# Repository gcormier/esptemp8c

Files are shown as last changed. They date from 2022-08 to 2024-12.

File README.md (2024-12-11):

# esptemp8c
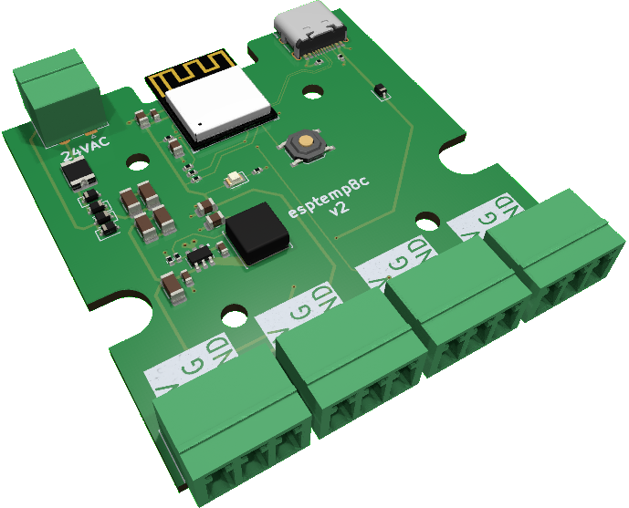
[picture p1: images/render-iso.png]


Open source, n-channel temperature logger using esphome for Dallas DS18B20 sensors. Powered by an ESP32-C3-MINI, it can be powered by USB-C or by 24VAC.



## Sensors
They can be found at various locations, including [DFRobot](https://www.dfrobot.com/product-689.html), [Adafruit](https://www.adafruit.com/product/381), Digikey or the usual suspects.

You will need to find out your sensor ID's as per the [esphome documentation](https://esphome.io/components/one_wire#one-wire).

### Counterfeit Sensors
If you are using a Dallas DS18B20 sensor, I strongly recommend using Digikey, Mouser or Adafruit to avoid obtaining [counterfeit sensors](https://github.com/cpetrich/counterfeit_DS18B20/tree/master).

## Powering
Only *one* power source should be used.
- USB-C Jack (5V)
- Screw terminal
    - It is designed for 24VAC. 12VAC is probably the minimum required for AC. Do not exceed 24VAC.
    - 9VDC will be the minimum required amount if using DC, and it has been tested up to 24VDC. 

A self-resetting polyfuse is included to protect HVAC equipment if sourcing 24VAC from these units. The polyfuse does NOT apply to power from the USB-C port, as the device supplying power should have overcurrent protection per the USB standard.

## Flashing / Programming
You must hold down the button while plugging in the device the first time to enter programming mode. The device will then show up as a USB device on your computer. You can then use the esphome flasher to flash the device.

Subsequent flashing does not require use of the button - it can be done via USBC or OTA as well.

## Enclosure
Fits in a [Hammond 1593KBK](https://www.hammfg.com/part/1593KBK). Or you can make your own enclosure and 3D-print it (contributions welcome).

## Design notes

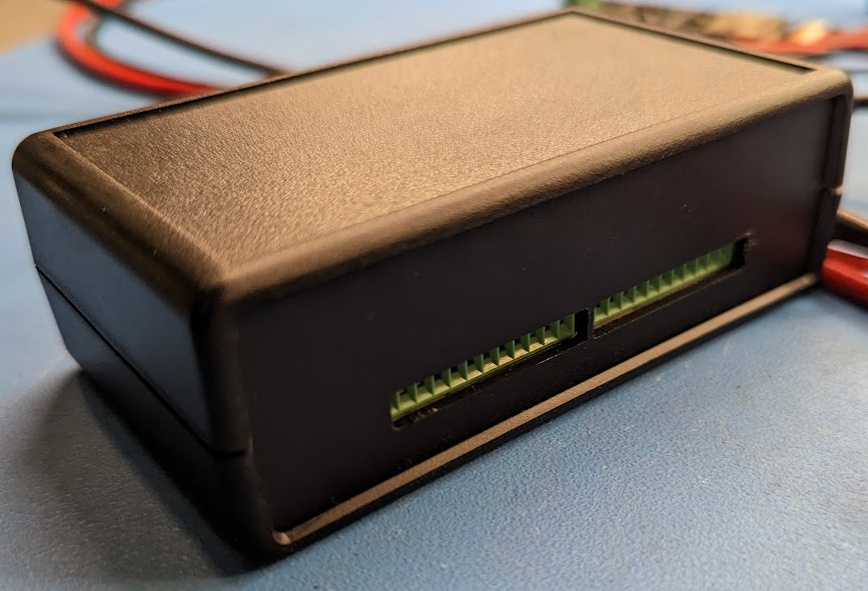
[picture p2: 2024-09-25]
images/case_v1.png

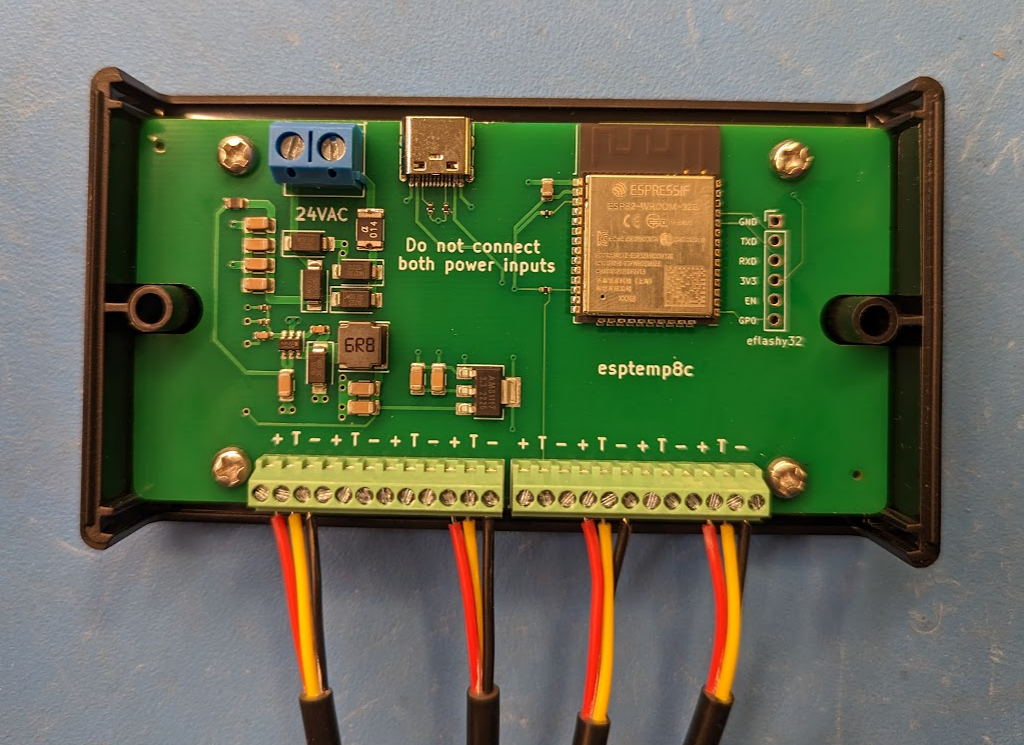
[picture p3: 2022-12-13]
images/esptemp8c_v1.png

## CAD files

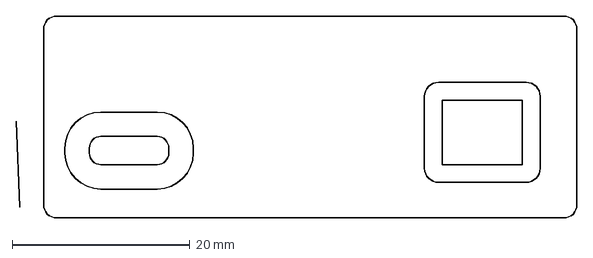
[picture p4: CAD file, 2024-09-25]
pcb/esptemp8c_panel1/panel1.dxf
63.1 x 22.7 mm

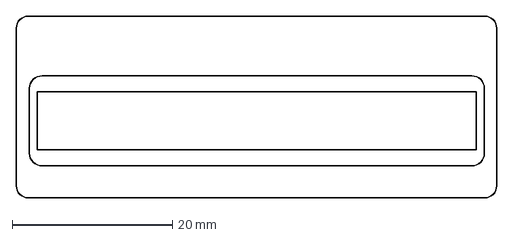
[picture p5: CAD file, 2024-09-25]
pcb/esptemp8c_panel2/panel2.dxf
60.0 x 22.7 mm

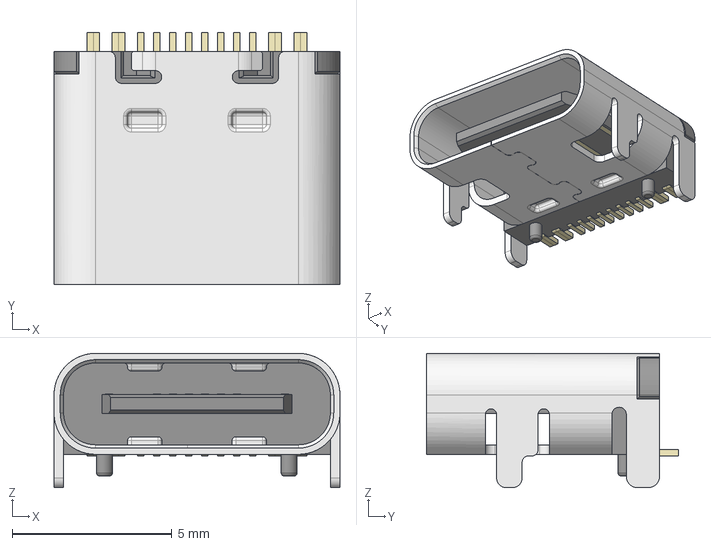
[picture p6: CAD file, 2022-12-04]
pcb/HRO_TYPE-C-31-M-12.step
8.95 x 7.90 x 4.20 mm

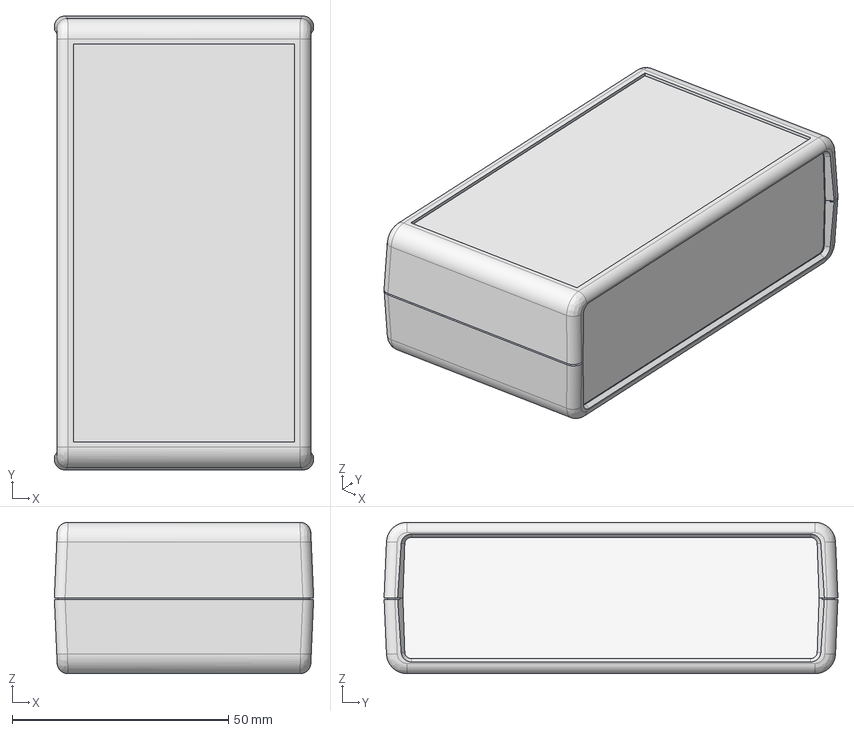
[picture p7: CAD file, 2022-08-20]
pcb/1593VBK.stp
60.0 x 105.0 x 35.0 mm
1593V Bottom v2
1593V End panel v1 x 2
1593V Top v2

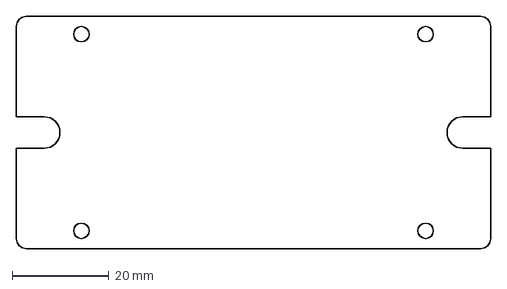
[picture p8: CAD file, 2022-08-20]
pcb/1593VBK_PCB.dxf
98.0 x 48.0 mm

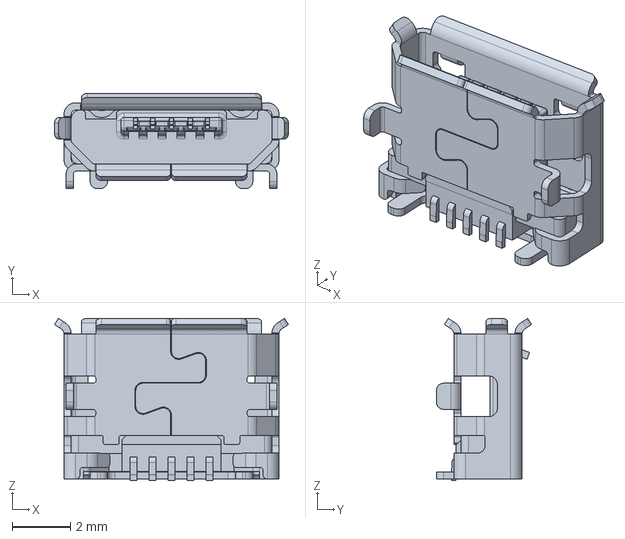
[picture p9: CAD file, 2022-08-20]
pcb/10118194c.stp
8.05 x 3.27 x 5.58 mm

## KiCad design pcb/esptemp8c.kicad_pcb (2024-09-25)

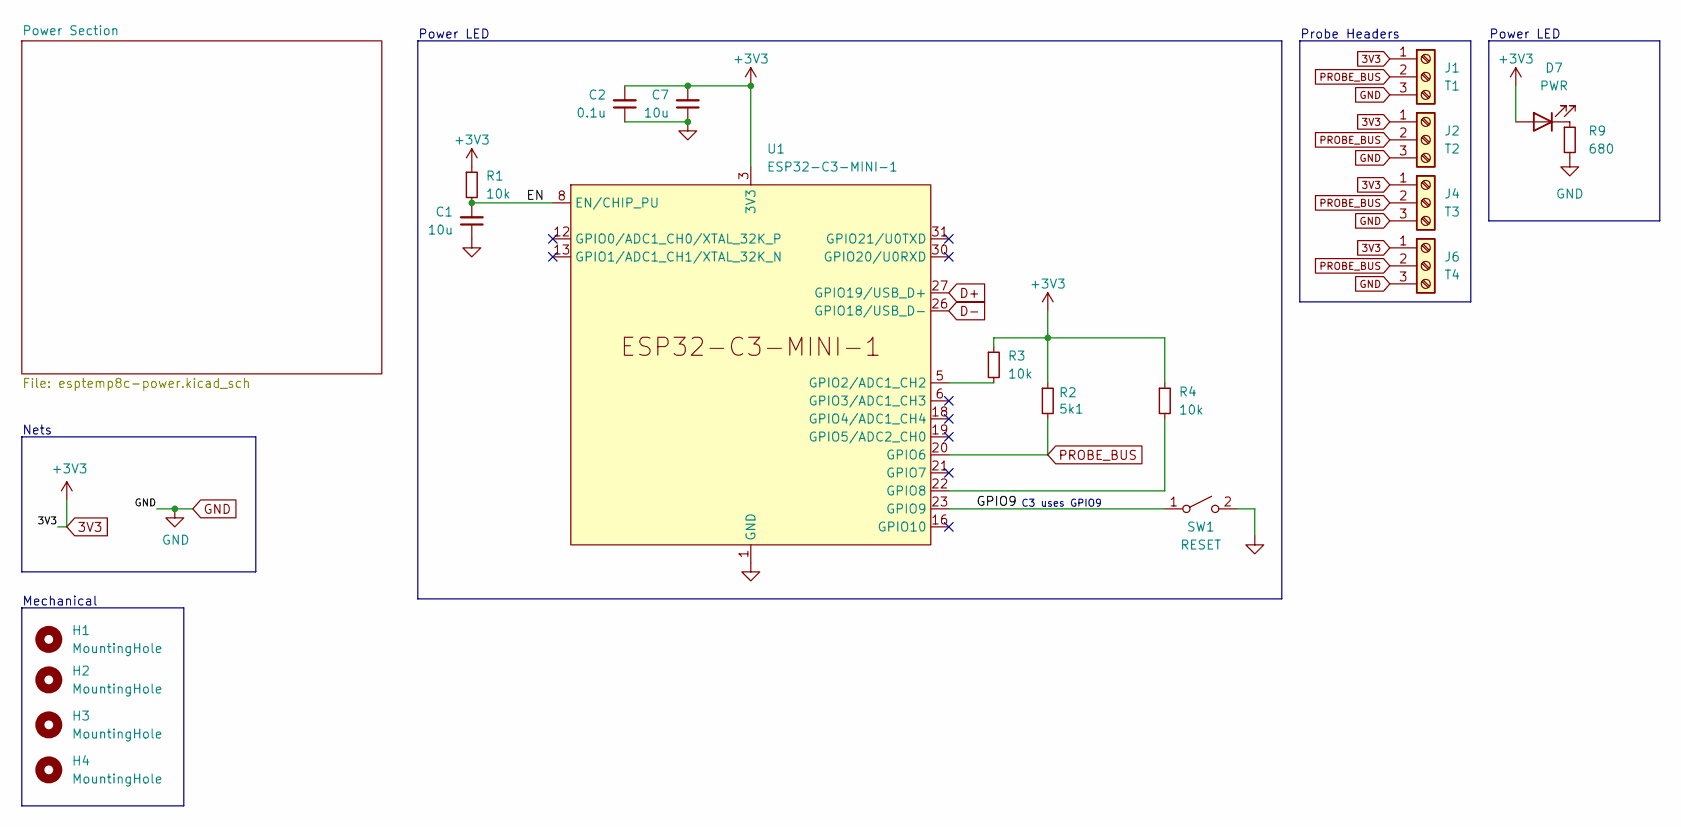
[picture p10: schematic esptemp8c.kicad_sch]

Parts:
C1, C7: 10u; C_0805_2012Metric; LCSC C15850
C2: 0.1u; C_0603_1608Metric; LCSC C14663
D7: PWR; LED_0805_2012Metric; LCSC C84256
H1, H2, H3, H4: MountingHole; MountingHole_3.2mm_M3
J1: T1; PhoenixContact_MC_1,5_3-G-3.81_1x03_P3.81mm_Horizontal; LCSC C8406
J2: T2; PhoenixContact_MC_1,5_3-G-3.81_1x03_P3.81mm_Horizontal; LCSC C8406
J4: T3; PhoenixContact_MC_1,5_3-G-3.81_1x03_P3.81mm_Horizontal; LCSC C8406
J6: T4; PhoenixContact_MC_1,5_3-G-3.81_1x03_P3.81mm_Horizontal; LCSC C8406
R1, R3, R4: 10k; R_0402_1005Metric; LCSC C25744
R2: 5k1; R_0402_1005Metric; LCSC C25905
R9: 680; R_0402_1005Metric; LCSC C25130
SW1: RESET; SW_Push_1P1T_XKB_TS-1187A; LCSC C318884
U1: ESP32-C3-MINI-1; LCSC C2838502

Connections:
3V3: C2.2, C7.2, D7.2 (A), J1.1, J2.1, J4.1, J6.1, R1.1, R2.1, R3.1, R4.1, U1.3 (3V3); also elsewhere on the board
/EN: C1.2, R1.2, U1.8 (EN/CHIP_PU)
/GPIO9: SW1.1 (A), U1.23 (GPIO9)
D+: U1.27 (GPIO19/USB_D+); also elsewhere on the board
D-: U1.26 (GPIO18/USB_D-); also elsewhere on the board
GND: C1.1, C2.1, C7.1, J1.3, J2.3, J4.3, J6.3, R9.2, SW1.2 (B), U1.1 (GND), U1.2 (GND), U1.11 (GND), U1.14 (GND), U1.36 (GND), U1.37 (GND), U1.38 (GND), U1.39 (GND), U1.40 (GND), U1.41 (GND), U1.42 (GND), U1.43 (GND), U1.44 (GND), U1.45 (GND), U1.46 (GND), U1.47 (GND), U1.48 (GND), U1.49 (GND), U1.50 (GND), U1.51 (GND), U1.52 (GND), U1.53 (GND); also elsewhere on the board
unnamed: D7.1 (K), R9.1
unnamed: R3.2, U1.5 (GPIO2/ADC1_CH2)
unnamed: R4.2, U1.22 (GPIO8)
PROBE_BUS: J1.2, J2.2, J4.2, J6.2, R2.2, U1.20 (GPIO6)

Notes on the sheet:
Nets
C3 uses GPIO9
Mechanical
Probe Headers
Power LED

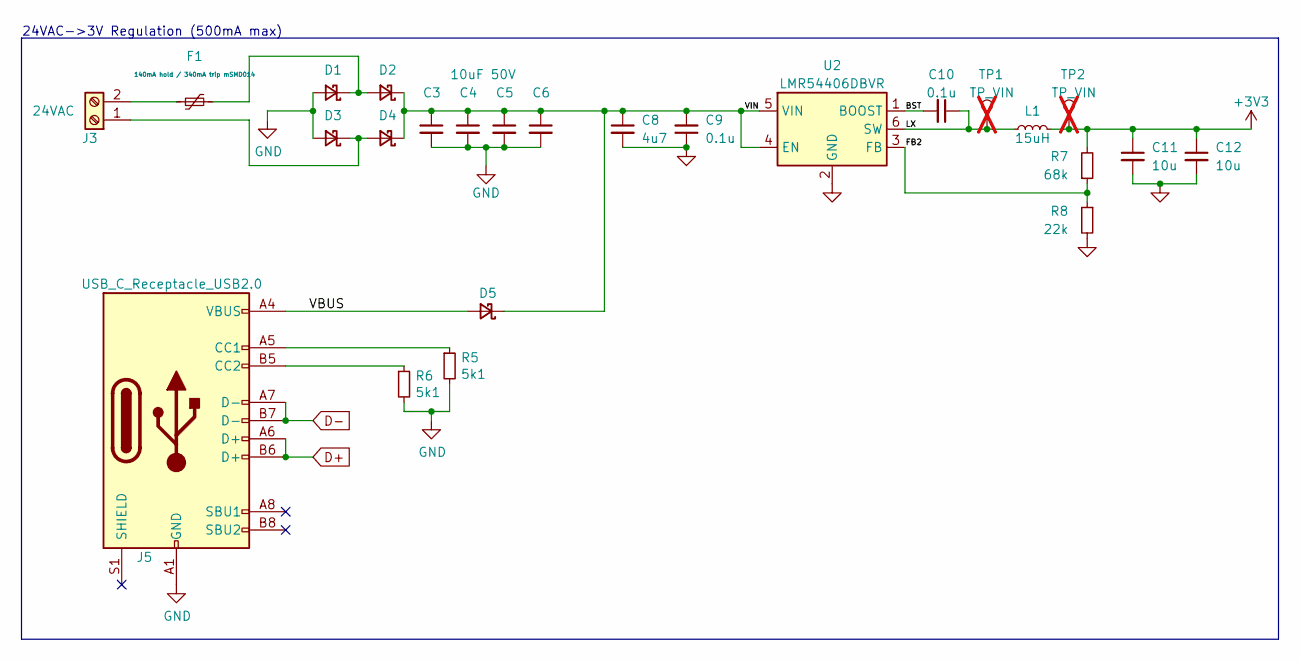
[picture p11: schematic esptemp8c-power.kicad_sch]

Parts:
C3, C4, C5, C6: 10uF 50V; C_1206_3216Metric; LCSC C13585
C8: 4u7; C_1206_3216Metric; LCSC C29823
C9, C10: 0.1u; C_0603_1608Metric; LCSC C14663
C11, C12: 10u; C_0805_2012Metric; LCSC C15850
D1, D2, D3, D4, D5: 1N5819WS; D_SOD-323; LCSC C191023
F1: 140mA hold / 340mA trip mSMD014; Fuse_1812_4532Metric; LCSC C70106
J3: 24VAC; PhoenixContact_MC_1,5_2-G-3.81_1x02_P3.81mm_Horizontal; LCSC C480537
J5: USB_C_Receptacle_USB2.0; USB_C_Receptacle_HRO_TYPE-C-31-M-12; LCSC C165948
L1: 15uH; L_Sunlord_SWPA6028S; LCSC C83373
R5, R6: 5k1; R_0402_1005Metric; LCSC C25905
R7: 68k; R_0402_1005Metric; LCSC C36871
R8: 22k; R_0402_1005Metric; LCSC C25768
TP1, TP2: TP_VIN; PinHeader_1x01_P2.54mm_Vertical; not fitted
U2: LMR54406DBVR; SOT-23-6; LCSC C5219316

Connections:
3V3: C11.1, C12.1, L1.2, R7.2, TP2.1; also elsewhere on the board
/Power Section/BST: C10.2, U2.1 (BOOST)
/Power Section/FB2: R7.1, R8.1, U2.3 (FB)
/Power Section/LX: C10.1, L1.1, TP1.1, U2.6 (SW)
/Power Section/VBUS: D5.2 (A), J5.A4 (VBUS), J5.A9 (VBUS), J5.B4 (VBUS), J5.B9 (VBUS)
/Power Section/VIN: C3.1, C4.1, C5.1, C6.1, C8.1, C9.2, D2.1 (K), D4.1 (K), D5.1 (K), U2.4 (EN), U2.5 (VIN)
D+: J5.A6 (D+), J5.B6 (D+); also elsewhere on the board
D-: J5.A7 (D-), J5.B7 (D-); also elsewhere on the board
GND: C3.2, C4.2, C5.2, C6.2, C8.2, C9.1, C11.2, C12.2, D1.2 (A), D3.2 (A), J5.A1 (GND), J5.A12 (GND), J5.B1 (GND), J5.B12 (GND), R5.2, R6.2, R8.2, U2.2 (GND); also elsewhere on the board
unnamed: D1.1 (K), D2.2 (A), F1.2
unnamed: D3.1 (K), D4.2 (A), J3.1
unnamed: F1.1, J3.2
unnamed: J5.A5 (CC1), R5.1
unnamed: J5.B5 (CC2), R6.1

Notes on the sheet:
24VAC->3V Regulation (500mA max)

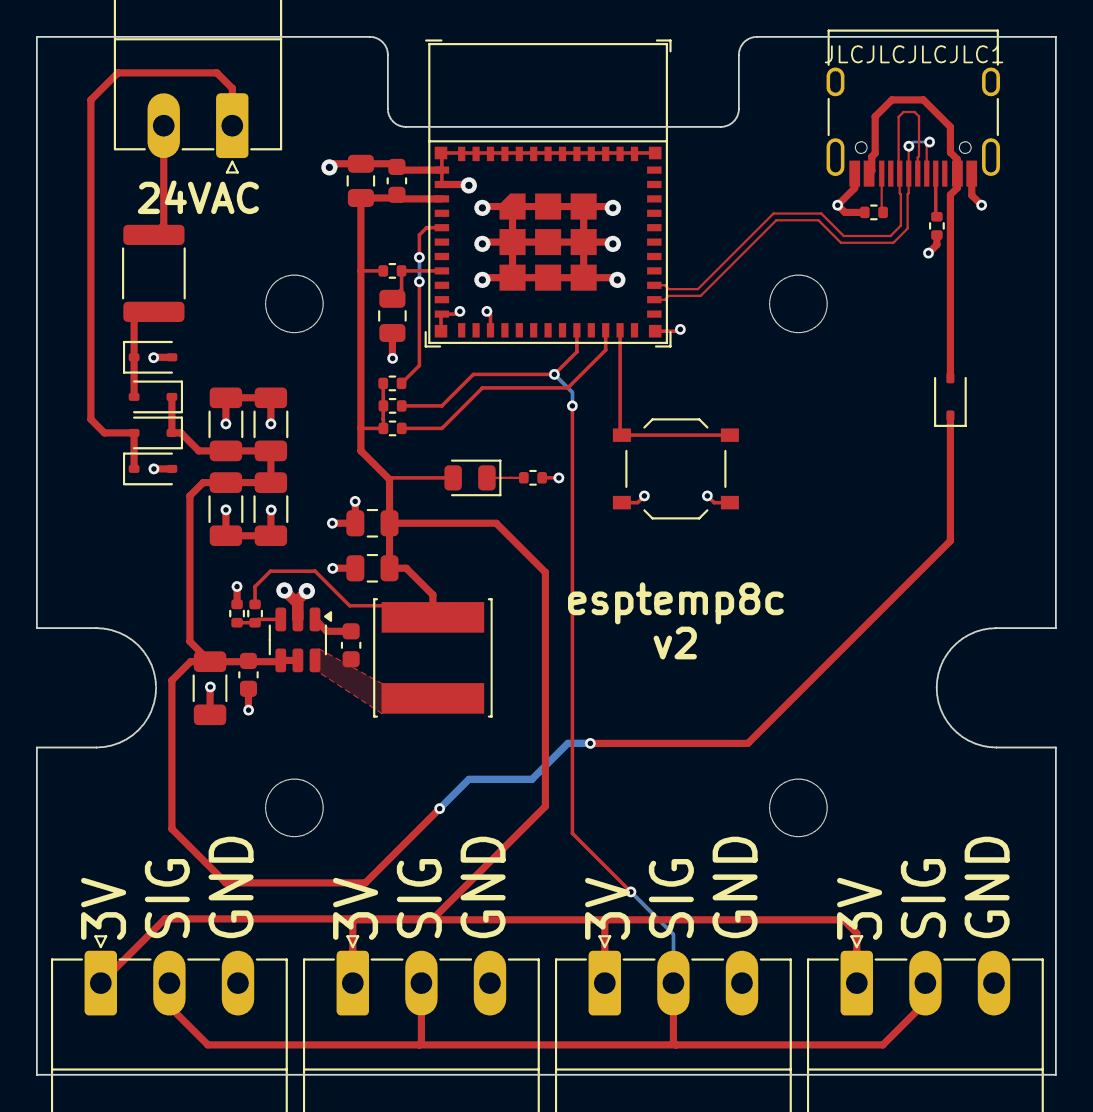
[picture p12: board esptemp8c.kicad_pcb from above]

Board: 2 copper layers, 56.6 x 57.7 mm, 42 parts (0 on the bottom side), 20 nets.

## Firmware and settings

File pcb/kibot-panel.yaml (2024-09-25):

kibot:
  version: 1

preflight:
  check_zone_fills: true
  fill_zones: true

outputs:
  - name: 'panel'
    type: panelize
    options:
      title: '+ (Panel)'
      units: mm
      configs:
        - layout:
            rows: 1
            cols: 2
            #vspace: 8
            #rotation: 90deg
          tabs:
            type: full
          cuts:
            type: vcuts
            layer: Edge.Cuts
            template: ''
          framing:
            type: railstb
            width: 5mm
            space: 3mm
            fillet: 1mm
            mintotalheight: 70mm
            mintotalwidth: 70mm
          tooling:
            type: 4hole
            hoffset: 5mm
            voffset: 2.5mm
            size: 2mm
          fiducials:
            type: 4fid
            hoffset: 15mm
            voffset: 3.85mm
            coppersize: 1mm
            opening: 2mm
          text:
            type: simple
            text: JLCJLCJLCJLC
            anchor: mt
            voffset: 2.5
            hjustify: center
            vjustify: center
          text2:
            type: simple
            text: Design created on {date} - <<hash>>
            anchor: mb
            voffset: -2.5
            hjustify: center
            vjustify: center
          post:
            refillzones: true
            origin: bl
            millradius: 0.6mm

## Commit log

2022-08-20 order number silkscreen
    [temp4c.kicad_pcb]
2022-08-20 lcsc PN for esp32
    [1593VBK.stp, temp4c.kicad_sch]
2022-08-21 switch rectifier
    [temp4c.kicad_pcb, temp4c.kicad_sch]
2022-08-21 esp32 custom rot
2022-12-04 esptemp8c rename
    [HRO_TYPE-C-31-M-12.step, temp4c-power.kicad_sch, temp4c.kicad_pcb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]
2022-12-04 fix ground pin on eflashy32
    [temp4c.kicad_pcb, temp4c.kicad_sch]
2022-12-04 silkscreen for eflashy32
    [temp4c.kicad_pcb]
2022-12-13 fix case
2024-08-01 updates for v2
    [esptemp8c-power.kicad_sch, esptemp8c.kicad_pcb, esptemp8c.kicad_sch]
2024-08-01 more v2 changes
    [KF2EDGK-2P.STEP, esptemp8c-power.kicad_sch, esptemp8c.kicad_pcb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]
2024-08-01 fix rounding
    [esptemp8c.kicad_pcb]
2024-08-01 docs and pics
    [esptemp8c-power.kicad_sch, esptemp8c.kicad_pcb]
2024-08-01 fix footprint to sot23
    [esptemp8c-power.kicad_sch]
2024-08-01 final touches and check
    [esptemp8c-power.kicad_sch, esptemp8c.kicad_pcb, esptemp8c.kicad_sch]
2024-08-02 add panels
    [esptemp8c_panel1.kicad_pcb, esptemp8c_panel1.kicad_sch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]
2024-08-02 panel touchup, alternate pn
    [esptemp8c.kicad_sch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]
